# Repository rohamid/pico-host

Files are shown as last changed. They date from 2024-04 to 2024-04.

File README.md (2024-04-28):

# PICO HOST #
RP2040 board inspired by [Adafruit's RP2040 Feather Host](https://learn.adafruit.com/adafruit-feather-rp2040-with-usb-type-a-host). Board features:
* JST XH Li-ion/Li-po battery connector.
* Battery charger circuit.
* USB A Female connector for [PIO based USB](https://github.com/sekigon-gonnoc/Pico-PIO-USB).
* Adafruit's `STEMMA QT` I2C connector.

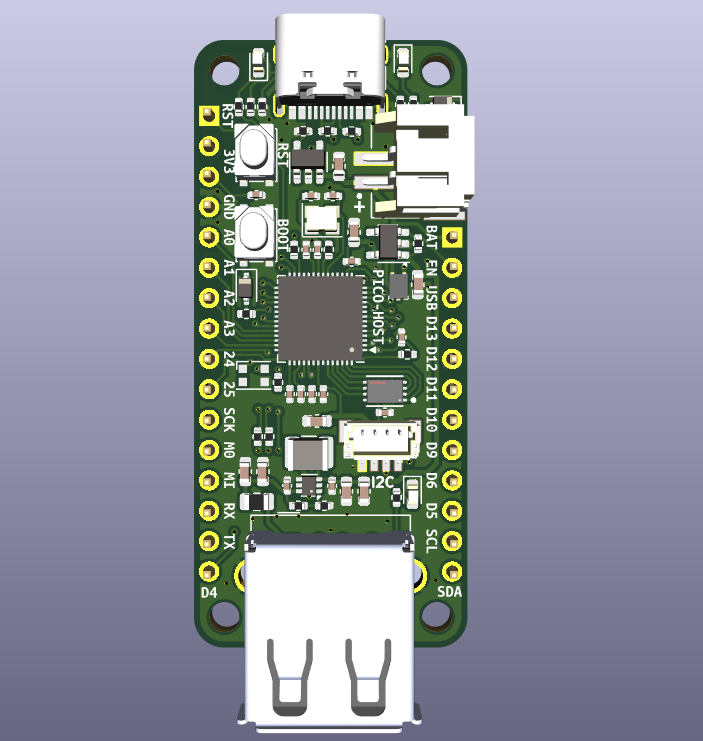
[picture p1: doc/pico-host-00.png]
pico-host-00


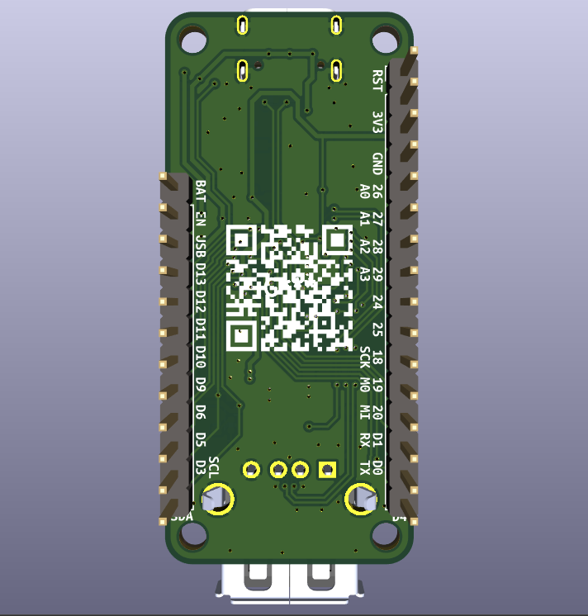
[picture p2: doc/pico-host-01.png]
pico-host-01


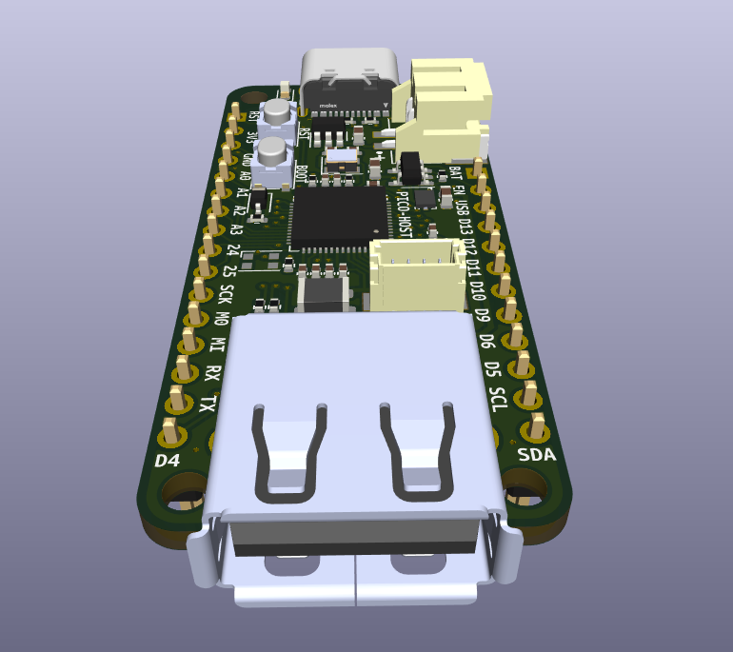
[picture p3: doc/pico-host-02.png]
pico-host-02


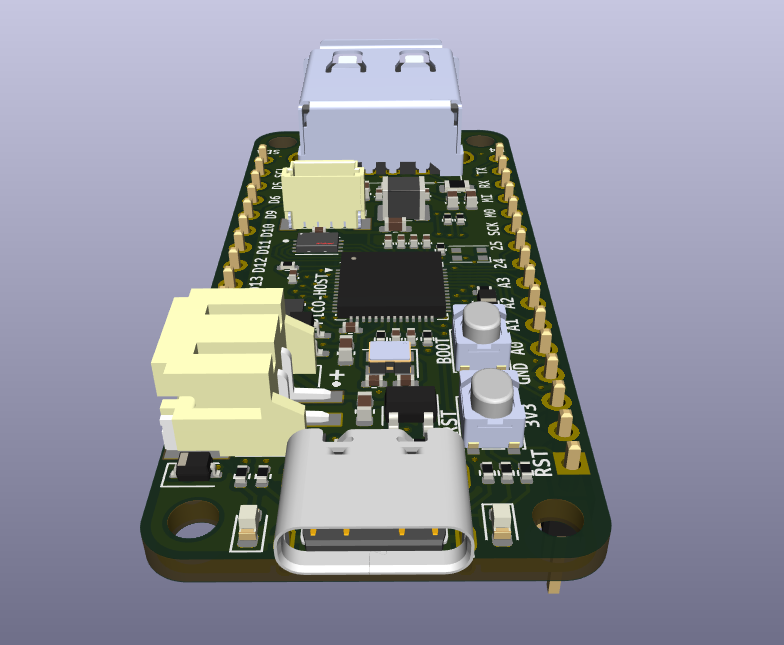
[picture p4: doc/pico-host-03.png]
pico-host-03


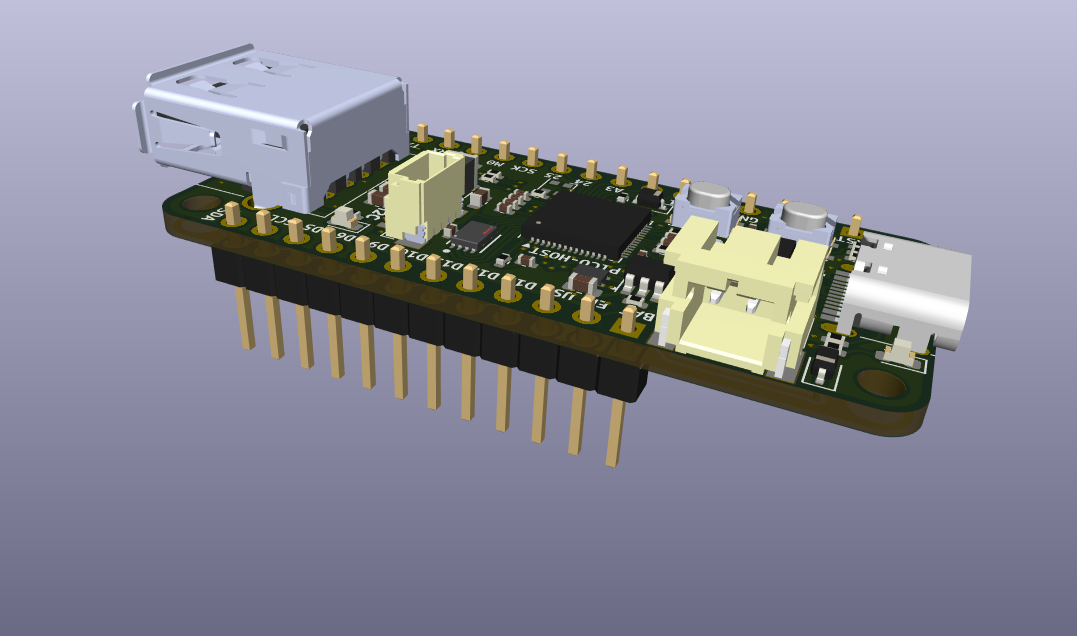
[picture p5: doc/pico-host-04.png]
pico-host-04


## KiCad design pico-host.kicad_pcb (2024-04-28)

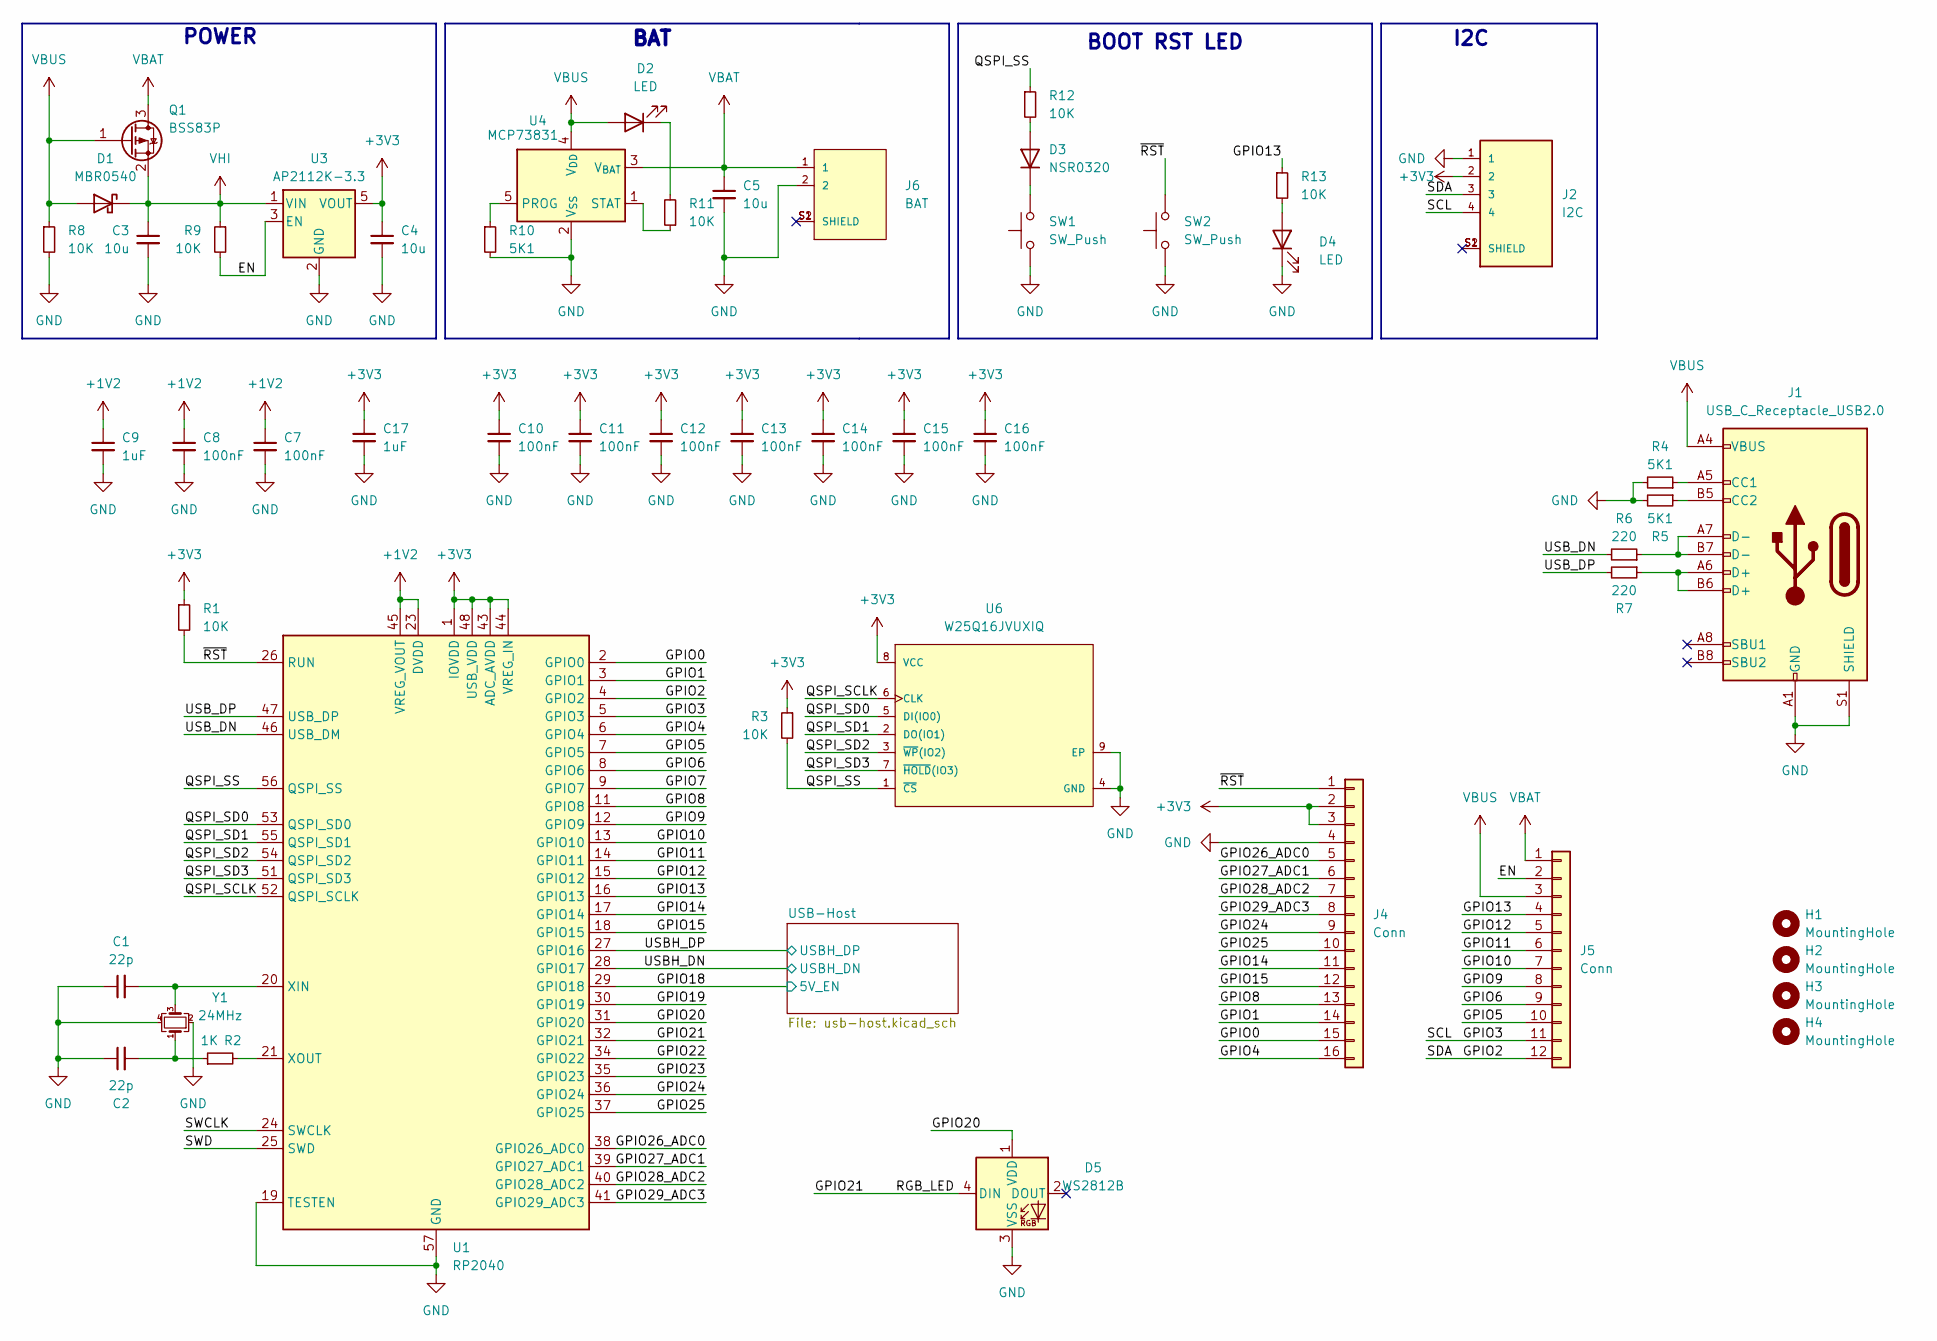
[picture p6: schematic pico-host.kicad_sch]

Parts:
C1, C2: 22p; C_0402_1005Metric
C3, C4, C5: 10u; C_0603_1608Metric
C7, C8, C10, C11, C12, C13, C14, C15, C16: 100nF; C_0402_1005Metric
C9: 1uF; C_0402_1005Metric
C17: 1uF; C_0603_1608Metric
D1: MBR0540; D_SOD-323
D2, D4: LED; LED_0603_1608Metric
D3: NSR0320; D_SOD-323
D5: WS2812B; LED_WS2812B-2020_PLCC4_2.0x2.0mm
H1, H2, H3, H4: MountingHole; MountingHole_2.5mm
J1: USB_C_Receptacle_USB2.0; USB_C_Receptacle_G-Switch_GT-USB-7010ASV
J2: I2C; JST_BM04B-SRSS-TB_LF__SN_
J4: Conn; PinHeader_1x16_P2.54mm_Vertical
J5: Conn; PinHeader_1x12_P2.54mm_Vertical
J6: BAT; JST_S2B-PH-SM4-TB_LF__SN_
Q1: BSS83P; TRANS_DMG3415UFY4Q-7
R1, R3, R8, R9, R11, R12, R13: 10K; R_0402_1005Metric
R2: 1K; R_0402_1005Metric
R4, R5, R10: 5K1; R_0402_1005Metric
R6, R7: 220; R_0402_1005Metric
SW1, SW2: SW_Push; SW_SPST_PTS810
U1: RP2040; QFN-56-1EP_7x7mm_P0.4mm_EP3.2x3.2mm
U3: AP2112K-3.3; SOT-23-5
U4: MCP73831; SOT-23-5
U6: W25Q16JVUXIQ; Winbond-UX-0-0-IPC_B; mouser part number 454-W25Q16JVUXIQTR; digikey description IC FLASH 16MBIT SPI/QUAD 8USON
Y1: 24MHz; Crystal_SMD_2520-4Pin_2.5x2.0mm

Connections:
+1V2: C7.1, C8.1, C9.1, U1.23 (DVDD), U1.45 (VREG_VOUT), U1.50 (DVDD)
+3V3: C4.1, C10.1, C11.1, C12.1, C13.1, C14.1, C15.1, C16.1, C17.1, J2.2, J4.2, J4.3, R1.1, R3.1, U1.1 (IOVDD), U1.10 (IOVDD), U1.22 (IOVDD), U1.33 (IOVDD), U1.42 (IOVDD), U1.43 (ADC_AVDD), U1.44 (VREG_IN), U1.48 (USB_VDD), U1.49 (IOVDD), U3.5 (VOUT), U6.8 (VCC); also elsewhere on the board
/EN: J5.2, R9.2, U3.3 (EN)
/GPIO0: J4.15, U1.2 (GPIO0)
/GPIO1: J4.14, U1.3 (GPIO1)
/GPIO2: J2.3, J5.12, U1.4 (GPIO2)
/GPIO3: J2.4, J5.11, U1.5 (GPIO3)
/GPIO4: J4.16, U1.6 (GPIO4)
/GPIO5: J5.10, U1.7 (GPIO5)
/GPIO6: J5.9, U1.8 (GPIO6)
/GPIO7: U1.9 (GPIO7)
/GPIO8: J4.13, U1.11 (GPIO8)
/GPIO9: J5.8, U1.12 (GPIO9)
/GPIO10: J5.7, U1.13 (GPIO10)
/GPIO11: J5.6, U1.14 (GPIO11)
/GPIO12: J5.5, U1.15 (GPIO12)
/GPIO13: J5.4, R13.1, U1.16 (GPIO13)
/GPIO14: J4.11, U1.17 (GPIO14)
/GPIO15: J4.12, U1.18 (GPIO15)
/GPIO18: U1.29 (GPIO18); also elsewhere on the board
/GPIO19: U1.30 (GPIO19)
/GPIO20: D5.1 (VDD), U1.31 (GPIO20)
/GPIO21: D5.4 (DIN), U1.32 (GPIO21)
/GPIO22: U1.34 (GPIO22)
/GPIO23: U1.35 (GPIO23)
/GPIO24: J4.9, U1.36 (GPIO24)
/GPIO25: J4.10, U1.37 (GPIO25)
/GPIO26_ADC0: J4.5, U1.38 (GPIO26_ADC0)
/GPIO27_ADC1: J4.6, U1.39 (GPIO27_ADC1)
/GPIO28_ADC2: J4.7, U1.40 (GPIO28_ADC2)
/GPIO29_ADC3: J4.8, U1.41 (GPIO29_ADC3)
/QSPI_SCLK: U1.52 (QSPI_SCLK), U6.6 (CLK)
/QSPI_SD0: U1.53 (QSPI_SD0), U6.5 (DI(IO0))
/QSPI_SD1: U1.55 (QSPI_SD1), U6.2 (DO(IO1))
/QSPI_SD2: U1.54 (QSPI_SD2), U6.3 (~WP(IO2))
/QSPI_SD3: U1.51 (QSPI_SD3), U6.7 (~HOLD(IO3))
/QSPI_SS: R3.2, R12.1, U1.56 (QSPI_SS), U6.1 (~CS)
/SWCLK: U1.24 (SWCLK)
/SWD: U1.25 (SWD)
/USBH_DN: U1.28 (GPIO17); also elsewhere on the board
/USBH_DP: U1.27 (GPIO16); also elsewhere on the board
/USB_DN: R6.2, U1.46 (USB_DM)
/USB_DP: R7.2, U1.47 (USB_DP)
/~RST: J4.1, R1.2, SW2.2, U1.26 (RUN)
GND: C1.1, C2.1, C3.2, C4.2, C5.2, C7.2, C8.2, C9.2, C10.2, C11.2, C12.2, C13.2, C14.2, C15.2, C16.2, C17.2, D4.1 (K), D5.3 (VSS), J1.A1 (GND), J1.A12 (GND), J1.B1 (GND), J1.B12 (GND), J1.S1 (SHIELD), J2.1, J4.4, J6.2, R4.2, R5.2, R8.2, R10.2, SW1.1, SW2.1, U1.19 (TESTEN), U1.57 (GND), U3.2 (GND), U4.2 (V_{SS}), U6.4 (GND), U6.9 (EP), Y1.2, Y1.4; also elsewhere on the board
unnamed: C2.2, R2.1, Y1.1
unnamed: D2.1 (K), R11.2
unnamed: D3.2 (A), R12.2
unnamed: D3.1 (K), SW1.2
unnamed: D4.2 (A), R13.2
unnamed: J1.A5 (CC1), R4.1
unnamed: J1.B5 (CC2), R5.1
unnamed: J1.A6 (D+), J1.B6 (D+), R7.1
unnamed: J1.A7 (D-), J1.B7 (D-), R6.1
unnamed: C1.2, U1.20 (XIN), Y1.3
unnamed: R2.2, U1.21 (XOUT)
unnamed: R10.1, U4.5 (PROG)
unnamed: R11.1, U4.1 (STAT)
VBAT: C5.1, J5.1, J6.1, Q1.3 (D), U4.3 (V_{BAT})
VBUS: D1.2 (A), D2.2 (A), J1.A4 (VBUS), J1.A9 (VBUS), J1.B4 (VBUS), J1.B9 (VBUS), J5.3, Q1.1 (G), R8.1, U4.4 (V_{DD})
VHI: C3.1, D1.1 (K), Q1.2 (S), R9.1, U3.1 (VIN); also elsewhere on the board

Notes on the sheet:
BAT
I2C
POWER
BOOT RST LED

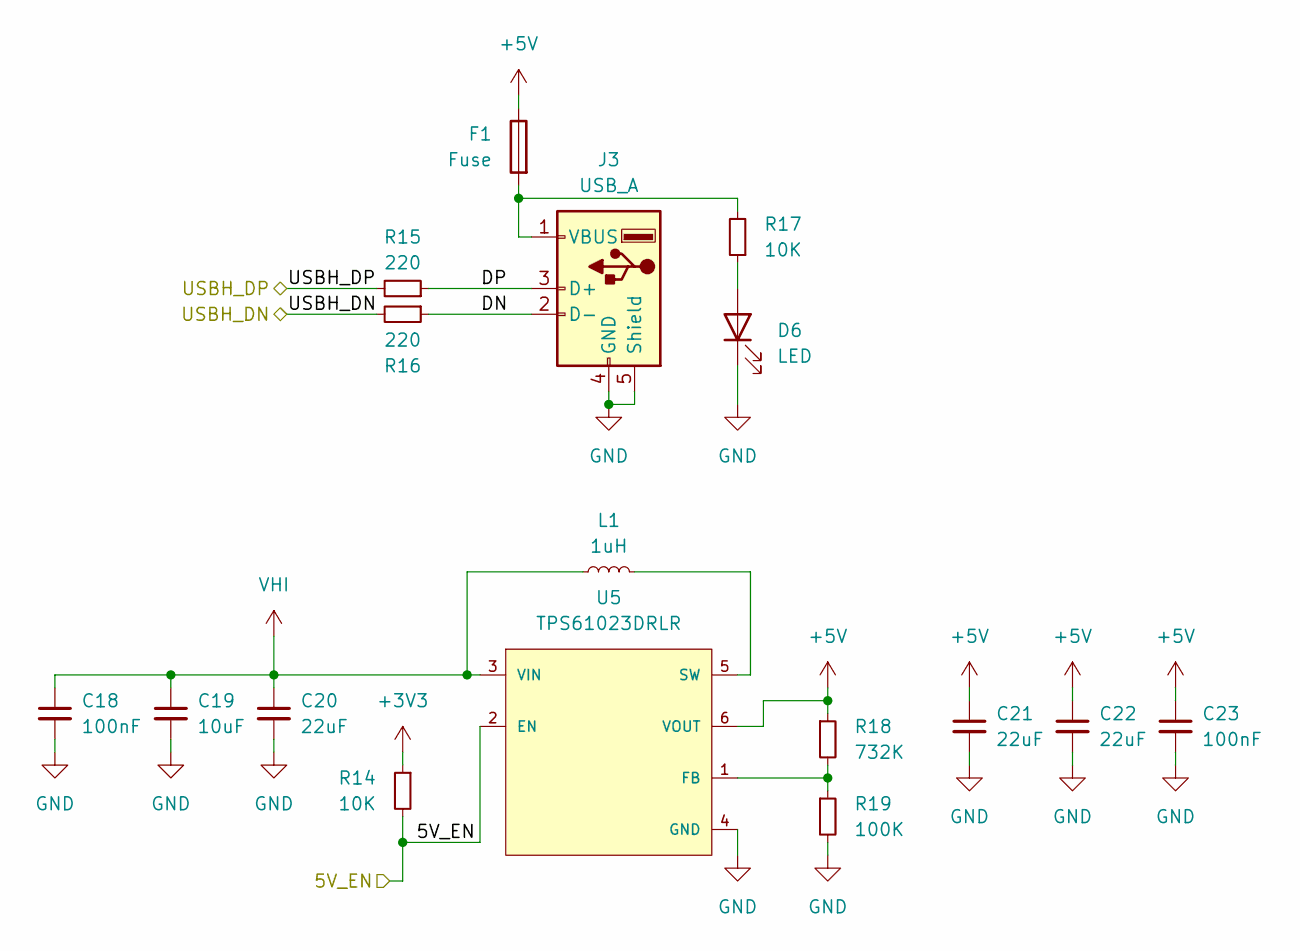
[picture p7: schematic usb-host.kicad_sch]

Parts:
C18, C23: 100nF; C_0402_1005Metric
C19: 10uF; C_0603_1608Metric
C20, C21, C22: 22uF; C_0603_1608Metric
D6: LED; LED_0603_1608Metric
F1: Fuse; Fuse_0805_2012Metric
J3: USB_A; USB_A_Molex_67643_Horizontal
L1: 1uH; L_1210_3225Metric
R14, R17: 10K; R_0402_1005Metric
R15, R16: 220; R_0402_1005Metric
R18: 732K; R_0402_1005Metric
R19: 100K; R_0402_1005Metric
U5: TPS61023DRLR; SOT-563; output voltage 2.2-5.5V; mouser part number 595-TPS61023DRLR; digikey description FINISH GOODS FOR TPS61023

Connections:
+3V3: R14.1; also elsewhere on the board
+5V: C21.1, C22.1, C23.1, F1.1, R18.1, U5.6 (VOUT)
/GPIO18: R14.2, U5.2 (EN); also elsewhere on the board
/USB-Host/DN: J3.2 (D-), R16.1
/USB-Host/DP: J3.3 (D+), R15.1
/USBH_DN: R16.2; also elsewhere on the board
/USBH_DP: R15.2; also elsewhere on the board
GND: C18.2, C19.2, C20.2, C21.2, C22.2, C23.2, D6.1 (K), J3.4 (GND), J3.5 (Shield), R19.2, U5.4 (GND); also elsewhere on the board
unnamed: D6.2 (A), R17.1
unnamed: F1.2, J3.1 (VBUS), R17.2
unnamed: R18.2, R19.1, U5.1 (FB)
unnamed: L1.2, U5.5 (SW)
VHI: C18.1, C19.1, C20.1, L1.1, U5.3 (VIN); also elsewhere on the board

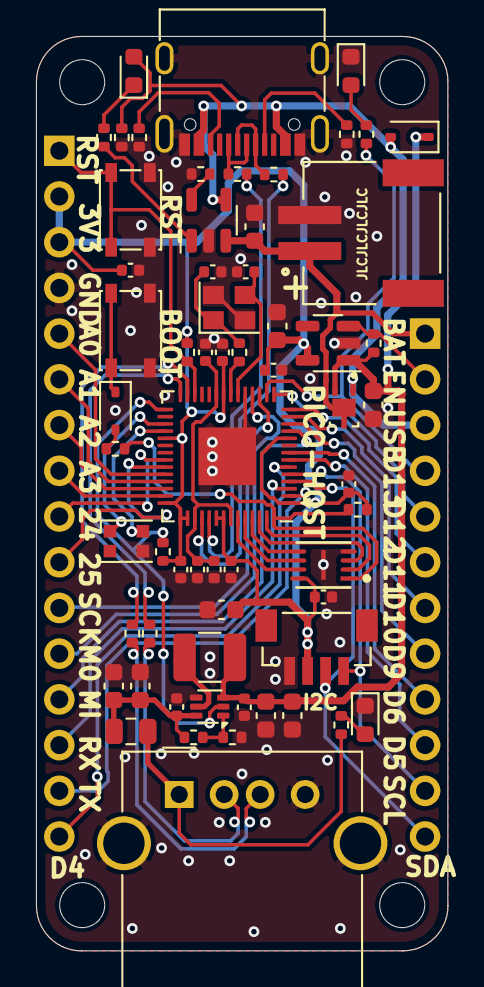
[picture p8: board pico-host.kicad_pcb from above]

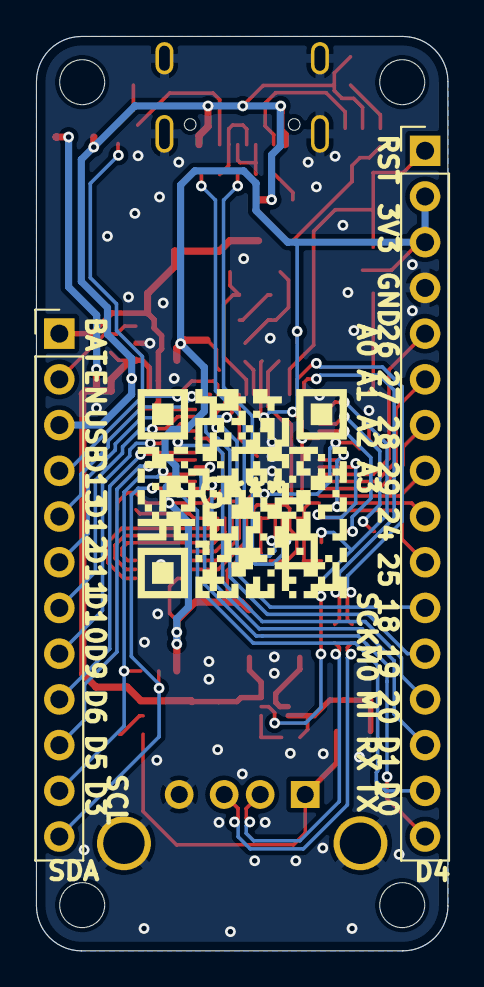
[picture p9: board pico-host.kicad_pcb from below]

Board: 2 copper layers, 22.9 x 50.8 mm, 68 parts (2 on the bottom side), 62 nets.

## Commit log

2024-03-18 Tracks almost finished
    [pico-host.kicad_pcb, pico-host.kicad_sch]
2024-03-19 Finished Tracks
    [pico-host.kicad_pcb, pico-host.kicad_sch]
2024-04-28 Added qr logo, doc/images, updated README
    [pico-host.kicad_pcb, pico-host.kicad_sch]
